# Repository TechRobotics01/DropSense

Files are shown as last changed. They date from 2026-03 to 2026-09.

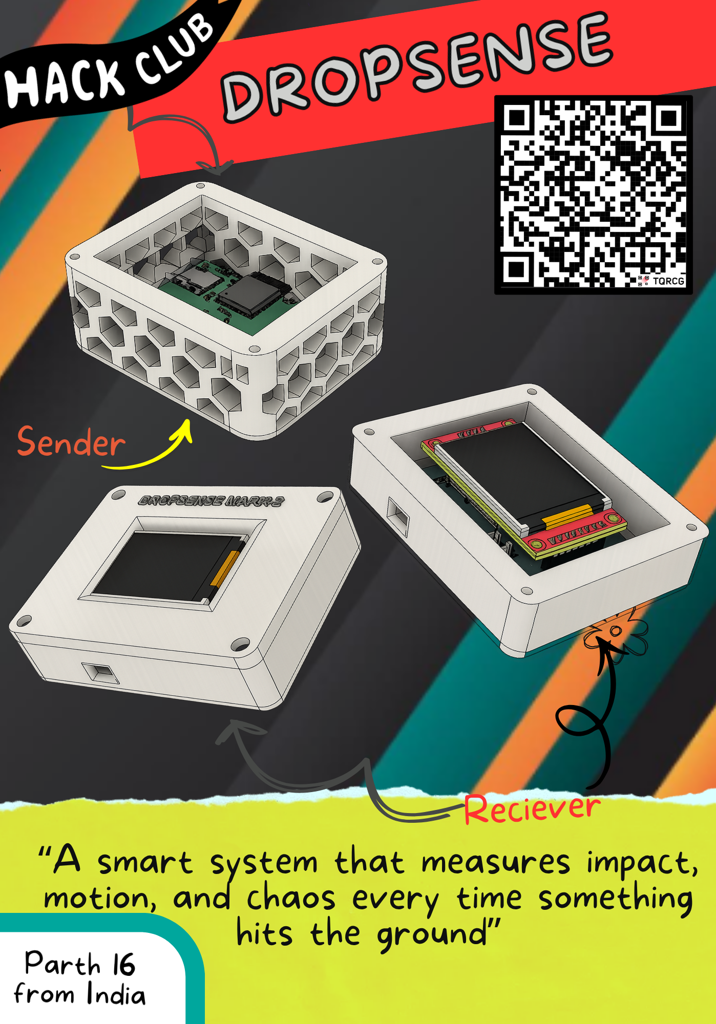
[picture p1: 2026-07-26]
Dropsense_V2/ZINE PAGE.png

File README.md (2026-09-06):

# DropSense
"what acctually happens when something drops"
dropsense answers that with data 

Dropsense is a wireless embedded system project which logs and transmits data in real time 
what type of data exactly?- it transmits the height from which it is dropped, the time period of the drop and the maximum Gforce which the device accelerated to during the impact .

Basically it consists of two parts the sender and the reciever 

# IMPORTANT POINT FOR THE REVIEWER
PLEASE CONSIDER THIS AS A DIGITAL DESIGN ONLY I DO NOT MEAN TO SUBMIT IT AS A IRL BUILD BUT A DIGITAL 2ND ITERATION OF THE PROJECT 
WHEN I BUILT THIS PROJECT IRL IT DID NOT WORK NOT BECAUSE IT WASN'T DESIGNED PROPERLY BUT BECAUSE AN IC FAILED AND WHICH I AM NOT ABLE TO REPLACE BECAUSE IT IS EXTREMELY COSTLY SO PLEASE CONSIDER THIS AS A DIGITAL DESIGN AND APPROVE IT 

# SENDER 
the sender consists of a custom made pcb which has a an esp32 s3 wroom 1 module an microsd card holder and a mpu6050(smd)
the sender will read the data and log it in sd card module and upomn impact that is g force greater than 5Gs then it will send info about the drop(height,time period etc) to the reciever btw this all is battery operated and it has a custom bms to power the pcb





This devise has hexagonal walls because they are better at abosrbing impacts!

# RECIEVER 
The reciever consists of an esp32 s3 wroom1 module and also an 1.8 inch tft display along with a custom made BMS for charging the battery which powers the pcb 
and the display shows all the info about the drop when it recieves the data fropm the sender 






# IRL BUILD 
## SENDER



## RECIEVER



## ZINE PAGE
DROPSENSE (2)

# Hardware
This device consists of 
1. MPU6050
2. Esp32-S3 module (not the development board)
3. sd card module 
4. custom BMS circuit
5. A small Li-Ion batter
6. 1.8 inch tft display 

All these parts will be on a custom made PCB whcih will be be enclosed inside a 3D printed case made out of TPU (you may also use PETG or CF-NYLON for added durability)

## THIS DEVICE HAS AN ERROR OF +-1CM FOR HEIGHT WHICH IS AM EXTREMELY LOW ERROR ##

# software
This was designed using the following softwares 

1. **Fusion360** for the 3d designing of the case
2. **KiCad** for the PCB design of this device

## CONTROL LOGIC
  1. in the prototyping stage
  2. The MPU6050 reads the values at a very high speed
  3. and then the valuse are logged into the sd card in a .csv file format
  4. then for prototyping the .csv file was read and analyzed
  5. figured out the threshold values such ad the gForce values which are required for automatic triggering and logging of data
  6. for eg when the device approached near 0 gForce vaklues the device is considered in a freefall and then the mpu605 starts to log the values in the sd card module and when the impact happend and the gForce stabelized at around 1Gfprce we can consider the device is stationary again and the Esp32 enters deep sleep mode again to save battery power
  7. the .csv file can then be used to plot graphs in different types of softwares for crash analysis
  8. also the crutial values such as drop height and maximum gForce of the crashb and the time time from falling to the crash is printed on the screen of the reciever 

## APPLICATIONS 
**this device can be used and applicated in places where gForce or acceleration and decelleration needs to be preciself analyzed**
1. drone crash analysis simply mount this device onto a drone and it will automaticaklly log the data when the drone crashes 
2. it can also be used in car crash analysis
3. this device acts as a black box for analysuis 

# credits (for R&D of this device)
google.com
https://randomnerdtutorials.com/arduino-mpu-6050-accelerometer-gyroscope/
Adafruit (use for taking out the values from mpu6050)
random nerd tutorials 
grabcad for the 3d step files of the tft and micro usb

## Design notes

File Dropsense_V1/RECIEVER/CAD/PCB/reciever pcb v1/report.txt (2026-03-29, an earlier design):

Plotted to 'C:\Users\DELL\Desktop\MISSION FALLOUT\DropSense\Dropsense_V1\RECIEVER\CAD\PCB\reciever pcb v1\reciever pcb v1-F_Cu.gbr'.
Plotted to 'C:\Users\DELL\Desktop\MISSION FALLOUT\DropSense\Dropsense_V1\RECIEVER\CAD\PCB\reciever pcb v1\reciever pcb v1-B_Cu.gbr'.
Plotted to 'C:\Users\DELL\Desktop\MISSION FALLOUT\DropSense\Dropsense_V1\RECIEVER\CAD\PCB\reciever pcb v1\reciever pcb v1-F_Paste.gbr'.
Plotted to 'C:\Users\DELL\Desktop\MISSION FALLOUT\DropSense\Dropsense_V1\RECIEVER\CAD\PCB\reciever pcb v1\reciever pcb v1-B_Paste.gbr'.
Plotted to 'C:\Users\DELL\Desktop\MISSION FALLOUT\DropSense\Dropsense_V1\RECIEVER\CAD\PCB\reciever pcb v1\reciever pcb v1-F_Silkscreen.gbr'.
Plotted to 'C:\Users\DELL\Desktop\MISSION FALLOUT\DropSense\Dropsense_V1\RECIEVER\CAD\PCB\reciever pcb v1\reciever pcb v1-B_Silkscreen.gbr'.
Plotted to 'C:\Users\DELL\Desktop\MISSION FALLOUT\DropSense\Dropsense_V1\RECIEVER\CAD\PCB\reciever pcb v1\reciever pcb v1-F_Mask.gbr'.
Plotted to 'C:\Users\DELL\Desktop\MISSION FALLOUT\DropSense\Dropsense_V1\RECIEVER\CAD\PCB\reciever pcb v1\reciever pcb v1-B_Mask.gbr'.
Plotted to 'C:\Users\DELL\Desktop\MISSION FALLOUT\DropSense\Dropsense_V1\RECIEVER\CAD\PCB\reciever pcb v1\reciever pcb v1-Edge_Cuts.gbr'.
Created Gerber job file 'C:\Users\DELL\Desktop\MISSION FALLOUT\DropSense\Dropsense_V1\RECIEVER\CAD\PCB\reciever pcb v1\reciever pcb v1-job.gbrjob'.
Info: Done.
Info: Done.

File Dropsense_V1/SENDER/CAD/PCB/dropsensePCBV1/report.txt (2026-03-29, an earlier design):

Plotted to 'C:\Users\DELL\Desktop\MISSION FALLOUT\DropSense\Dropsense_V1\SENDER\CAD\PCB\FINAL PERFECTED PCB FILE\dropsensePCBV1-F_Cu.gbr'.
Plotted to 'C:\Users\DELL\Desktop\MISSION FALLOUT\DropSense\Dropsense_V1\SENDER\CAD\PCB\FINAL PERFECTED PCB FILE\dropsensePCBV1-B_Cu.gbr'.
Plotted to 'C:\Users\DELL\Desktop\MISSION FALLOUT\DropSense\Dropsense_V1\SENDER\CAD\PCB\FINAL PERFECTED PCB FILE\dropsensePCBV1-F_Paste.gbr'.
Plotted to 'C:\Users\DELL\Desktop\MISSION FALLOUT\DropSense\Dropsense_V1\SENDER\CAD\PCB\FINAL PERFECTED PCB FILE\dropsensePCBV1-B_Paste.gbr'.
Plotted to 'C:\Users\DELL\Desktop\MISSION FALLOUT\DropSense\Dropsense_V1\SENDER\CAD\PCB\FINAL PERFECTED PCB FILE\dropsensePCBV1-F_Silkscreen.gbr'.
Plotted to 'C:\Users\DELL\Desktop\MISSION FALLOUT\DropSense\Dropsense_V1\SENDER\CAD\PCB\FINAL PERFECTED PCB FILE\dropsensePCBV1-B_Silkscreen.gbr'.
Plotted to 'C:\Users\DELL\Desktop\MISSION FALLOUT\DropSense\Dropsense_V1\SENDER\CAD\PCB\FINAL PERFECTED PCB FILE\dropsensePCBV1-F_Mask.gbr'.
Plotted to 'C:\Users\DELL\Desktop\MISSION FALLOUT\DropSense\Dropsense_V1\SENDER\CAD\PCB\FINAL PERFECTED PCB FILE\dropsensePCBV1-B_Mask.gbr'.
Plotted to 'C:\Users\DELL\Desktop\MISSION FALLOUT\DropSense\Dropsense_V1\SENDER\CAD\PCB\FINAL PERFECTED PCB FILE\dropsensePCBV1-Edge_Cuts.gbr'.
Created Gerber job file 'C:\Users\DELL\Desktop\MISSION FALLOUT\DropSense\Dropsense_V1\SENDER\CAD\PCB\FINAL PERFECTED PCB FILE\dropsensePCBV1-job.gbrjob'.
Info: Done.
Info: Done.

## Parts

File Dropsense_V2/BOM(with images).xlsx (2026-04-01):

Component | Quantity needed | Quantity purchased | Unit pricce($) | Total cost($) | Product link
100nF ±10% 50V Ceramic Capacitor X7R 0805 | 10 | 100 | 0.0051 | 0.51 | https://www.lcsc.com/product-detail/C49678.html
10uF ±10% 50V Ceramic Capacitor X5R 0805 | 10 | 50 | 0.072 | 3.6 | https://www.lcsc.com/product-detail/C440198.html
100uF ±20% 6.3V Ceramic Capacitor X5R 0805 | 10 | 20 | 0.2368 | 4.74 | https://www.lcsc.com/product-detail/C141660.html
Diode 40V 500mA Surface Mount 0805 | 10 | 10 | 0.1649 | 1.65 | https://www.lcsc.com/product-detail/C28323.html
Green 520nm LED Indication - Discrete 2.5V~3.6V 0805 | 1 | 30 | 0.0217 | 0.65 | https://www.lcsc.com/product-detail/C143774.html
Red 645nm LED Indication - Discrete 1.8V~2.4V 0805 | 1 | 100 | 0.0079 | 0.79 | https://www.lcsc.com/product-detail/C84260.html
SMD USB, DVI, HDMI Connector Adapters RoHS | 1 | 10 | 0.0828 | 0.83 | https://www.lcsc.com/product-detail/C19171391.html
Connector Header 2 position 2.5mm Pitch 3A Through Hole -25℃~+85℃ | 2 | 20 | 0.0373 | 0.75 | https://www.lcsc.com/product-detail/C53121380.html
330Ω ±1% 125mW 0805 Thick Film Resistor | 2 | 100 | 0.0023 | 0.23 | https://www.lcsc.com/product-detail/C158012.html
1.2Ω ±1% 125mW 0805 Thick Film Resistor | 2 | 100 | 0.0027 | 0.27 | https://www.lcsc.com/product-detail/C17630.html
4.7Ω ±1% 125mW 0805 Thick Film Resistor | 1 | 100 | 0.0027 | 0.27 | https://www.lcsc.com/product-detail/C2933356.html
10Ω 125mW 150V Thick Film Resistor ±1% ±200ppm/℃ 0805 Chip Resistor - Surface Mount RoHS | 2 | 100 | 0.008 | 0.8 | https://www.lcsc.com/product-detail/C2933459.html
Micro SD card (TF card) Connector and Ejector Push-Push Surface Mount | 2 | 2 | 1.6306 | 3.26 | https://www.lcsc.com/product-detail/C96347.html
QFN-24-EP(4x4) Accelerometers RoHS | 2 | 1 | 7.9306 | 7.93 | https://www.lcsc.com/product-detail/C114218.html
2.4GHz ESP32-S3 On-board PCB Antenna -103.5dBm SMD,25.5x18mm RF Transceiver Modules and Modems RoHS | 1 | 2 | 4.4597 | 8.92 | https://www.lcsc.com/product-detail/C24112.html
Lithium Battery 1A ESOP-8 Battery Management RoHS | 2 | 10 | 0.1828 | 1.83 | https://www.lcsc.com/product-detail/C2913197.html
3.3V 6V Positive Fixed SOT-23-5 Voltage Regulators - Linear, Low Drop Out (LDO) Regulators RoHS | 2 | 10 | 0.0491 | 0.49 | https://www.lcsc.com/product-detail/C16581.html
1uF ±10% 50V Ceramic Capacitor X7R 0805 | 2 | 100 | 0.0138 | 1.38 | https://www.lcsc.com/product-detail/C82942.html
WLY752530 3.7V 500mAh 1S LiPo Battery | 2 | 2 | 2.79 | 5.58 | https://robu.in/product/500mah-pcm-protected-micro-li-po-battery/
LCSC SHIPPING COST (CHEAPEST OPTION UPS) | 1 | 1 | $29.24 | 29.24
PCBs FABRICATION (from LION CIRCUITS )(sender and reciever both included) | 2 | 10 | 9.6 | 22.4(inc. GST) | https://order.lioncircuits.com/cart
1.8inch tft display | 1 | N/A | N/A | N/A | Self sourced
YIHUA 946D-IV Mini Soldering Hot Plate 400°C | 1 | 1 | 20.37 | 20.37 | https://babaocamachine.com/product/yihua-946d-iv-mini-soldering-hot-plate-400c-adjustable-temp-c-f-conversion/
solder paste | 1 | 1 | 1.8 | 1.8 | https://makerbazar.in/products/mechanic-10cc-lead-free-no-clean-solder-flux-paste-syring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
 |  |  | TOTAL COST = | 116.49

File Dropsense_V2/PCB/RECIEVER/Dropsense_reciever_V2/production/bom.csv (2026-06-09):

Designator | Footprint | Quantity | Value | LCSC Part #
C1, C2, C3, C4, C6 | 0805 | 5 | 10uF
C10, C5 | 0805 | 2 | 0.1uF
C12 | 0805 | 1 | 1uF
D3 | 0805 | 1 | red
D4 | 0805 | 1 | grn
EN1, IO0 | SW_Push_1P1T-SH_NO_CK_KMR2xxG | 2 | SW_Push
J1 | USB_Micro-B_Amphenol_10118194-0001LF_Horizontal | 1 | USB_B_Micro
J2 | JST_XH_B2B-XH-A_1x02_P2.50mm_Vertical | 1 | Battery_conn
J3 | PinSocket_1x08_P2.54mm_Vertical | 1 | 1.8inch TFT connector
R1 | 0805 | 1 | 3.3kR
R10, R11 | 0805 | 2 | 100kR
R2, R3 | 0805 | 2 | 1kR
R4, R5 | 0805 | 2 | 22R
R6, R7, R9 | 0805 | 3 | 10kR
R8 | 0805 | 1 | 330R
U1 | SOIC-8-1EP_3.9x4.9mm_P1.27mm_EP2.41x3.3mm_ThermalVias | 1 | TP4056-42-ESOP8
U2 | SOT-23-5 | 1 | ME6211C33M5
U3 | ESP32-S3-WROOM-1 | 1 | ESP32-S3-WROOM-1

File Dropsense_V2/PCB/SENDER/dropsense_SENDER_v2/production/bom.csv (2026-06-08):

Designator | Footprint | Quantity | Value | LCSC Part #
C1_2, C1, C11, C13, C3, C8 | 0805 | 6 | 10uF
C10, C2, C6, C7, C9 | 0805 | 5 | 0.1uF
C12 | 0805 | 1 | 1uF
C4 | 0805 | 1 | 2.2nF
C5 | 0805 | 1 | 100nF
D1 | 0805 | 1 | GREEN
D2 | 0805 | 1 | RED
EN1, IO0 | SW_Push_1P1T-SH_NO_CK_KMR2xxG | 2 | SW_Push
J1 | USB_Micro-B_Molex-105017-0001 | 1 | USB_B_Micro
J2 | JST_XH_B2B-XH-A_1x02_P2.50mm_Vertical | 1 | Conn_01x02
J3 | microSD_HC_Hirose_DM3AT-SF-PEJM5 | 1 | Micro_SD_Card_Det_Hirose_DM3AT
J4 | PinHeader_1x06_P2.54mm_Vertical | 1 | Conn_01x06_Pin
R1 | 0805 | 1 | 3.3kR
R10, R11 | 0805 | 2 | 100kR
R12, R13 | 0805 | 2 | 22R
R2, R3 | 0805 | 2 | 330R
R4, R5, R8, R9 | 0805 | 4 | 10kR
R6, R7 | 0805 | 2 | 4.7kR
U1 | ESP32-S3-WROOM-1 | 1 | ESP32-S3-WROOM-1
U2 | SOIC-8-1EP_3.9x4.9mm_P1.27mm_EP2.41x3.3mm_ThermalVias | 1 | TP4056-42-ESOP8
U3 | SOT-23-5 | 1 | ME6211C33M5
U4 | InvenSense_QFN-24_4x4mm_P0.5mm | 1 | MPU-6050

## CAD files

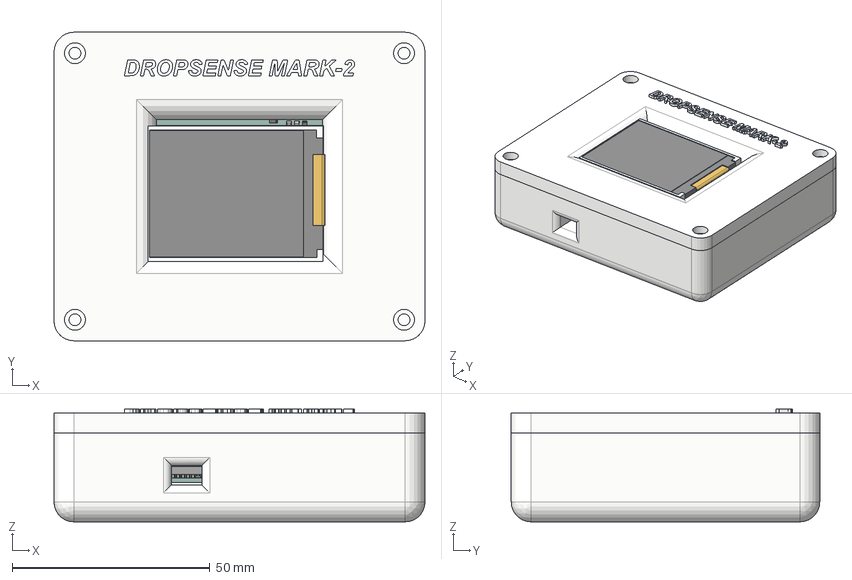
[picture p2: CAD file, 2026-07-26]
Dropsense_V2/CAD/RECIEVER/Reciever files/Dropsense Makr-2 reciever assembly v1.step
93.8 x 78.0 x 28.5 mm
R_0805_2012Metric x 11
PinSocket_1x08_P2.54mm_Vertical
C_0805_2012Metric x 8
ESP32-S3-WROOM-1
SW_Push_1P1T-SH_NO_CK_KMR2xxG x 2
JST_XH_B2B-XH-A_1x02_P2.50mm_Vertical
SOT-23-5
LED_0805_2012Metric x 2
dropsense_reciever_v2_PCB
Board~fHK2
TopSilkscreen~fHK2
BottomSilkscreen~fHK2
R0603~R0603~fHK2 x 4
SOT-23-3_L2.9-W1.3-P1.90-LS2.4-BR~SOT-23-3P_L2.9-W1.3-H1.0-LS2.4-P0.9 5~fHK2
HDR-TH_4P-P2.54-V-M~HDR-TH_4P-P2.54-M-LI-1X4P~fHK2
SD-CARD-SMD_SD-CARD-11P~SD-CARD-SMD_SD-CARD-11P~fHK2
C0603~C0603_L1.6-W0.8-H0.8~fHK2
HDR-TH_8P-P2.54-V-M~HDR-TH_8P-P2.54-V-M~fHK2
Dropsense mark-2 reciever part-1
Dropsense Mark-2 reciever part-2

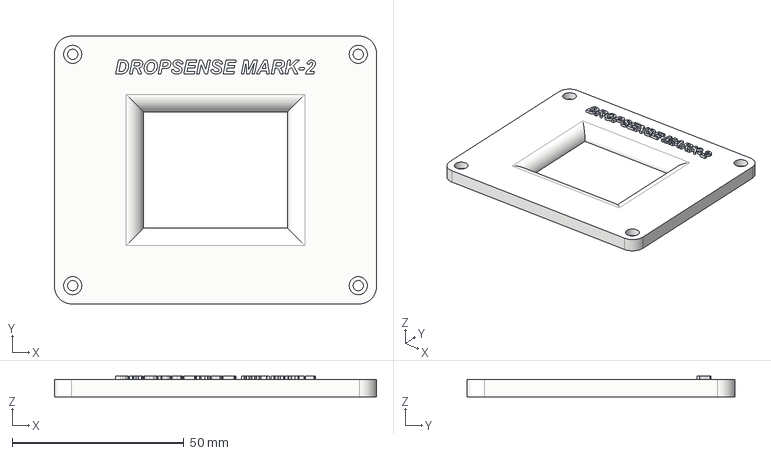
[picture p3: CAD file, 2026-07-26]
Dropsense_V2/CAD/RECIEVER/Reciever files/Dropsense Mark-2 reciever part-2 v8.step
93.8 x 78.0 x 6.00 mm

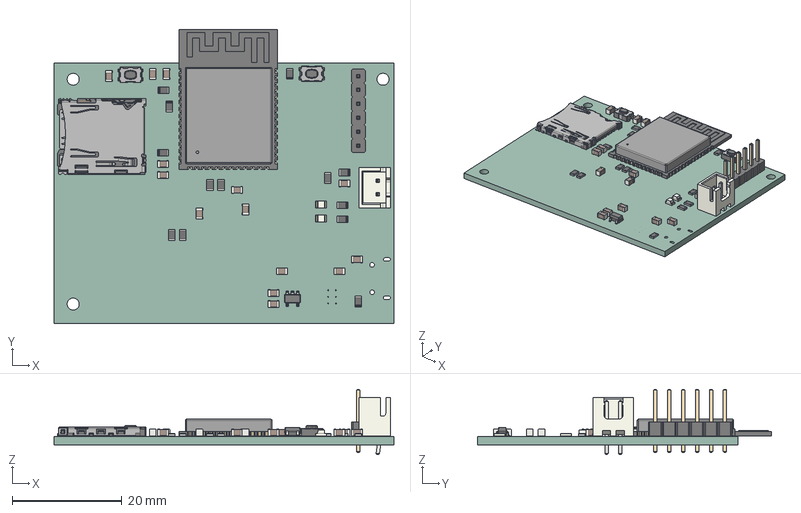
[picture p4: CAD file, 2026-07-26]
Dropsense_V2/CAD/SENDER/dropsense_v2.step
62.0 x 53.5 x 11.9 mm
C_0805_2012Metric x 14
R_0805_2012Metric x 13
SOT-23-5
LED_0805_2012Metric x 2
SW_Push_1P1T-SH_NO_CK_KMR2xxG x 2
ESP32-S3-WROOM-1
microSD_HC_Hirose_DM3AT-SF-PEJM5
PinHeader_1x06_P2.54mm_Vertical
JST_XH_B2B-XH-A_1x02_P2.50mm_Vertical
dropsense_v2_PCB

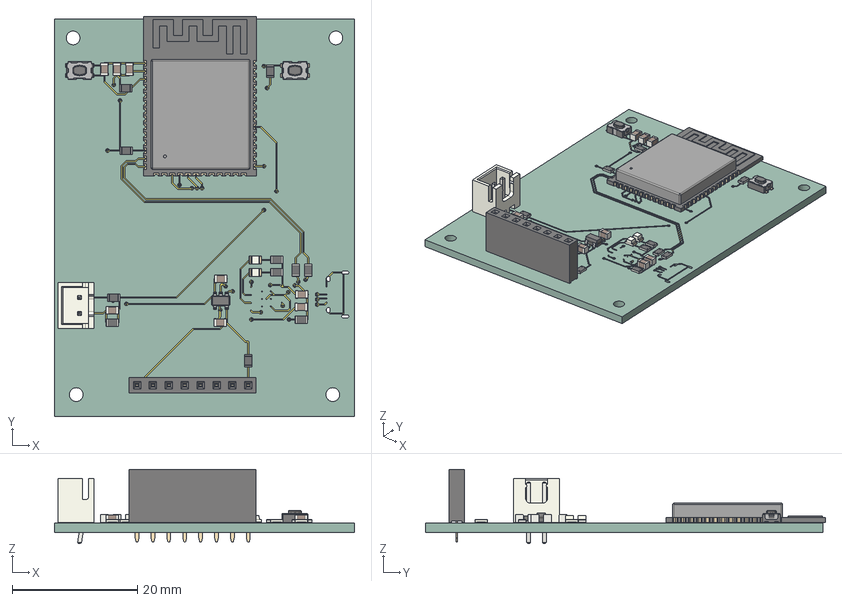
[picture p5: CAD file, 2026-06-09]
Dropsense_V2/PCB/RECIEVER/Dropsense_reciever_V2/RECIEVER STEP FILE/dropsense_reciever_v2.step
48.0 x 63.9 x 11.9 mm
R_0805_2012Metric x 11
PinSocket_1x08_P2.54mm_Vertical
C_0805_2012Metric x 8
ESP32-S3-WROOM-1
SW_Push_1P1T-SH_NO_CK_KMR2xxG x 2
JST_XH_B2B-XH-A_1x02_P2.50mm_Vertical
SOT-23-5
LED_0805_2012Metric x 2
dropsense_reciever_v2_copper
dropsense_reciever_v2_via
dropsense_reciever_v2_PCB

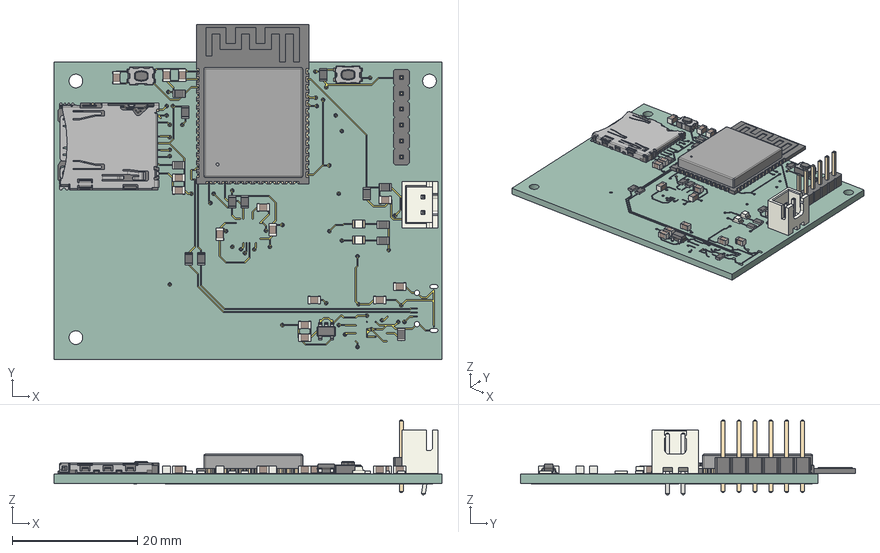
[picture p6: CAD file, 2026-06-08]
Dropsense_V2/PCB/SENDER/dropsense_SENDER_v2/PCB STEP FILE/dropsense_v2.step
62.0 x 53.5 x 11.9 mm
C_0805_2012Metric x 14
R_0805_2012Metric x 13
SOT-23-5
LED_0805_2012Metric x 2
SW_Push_1P1T-SH_NO_CK_KMR2xxG x 2
ESP32-S3-WROOM-1
microSD_HC_Hirose_DM3AT-SF-PEJM5
PinHeader_1x06_P2.54mm_Vertical
JST_XH_B2B-XH-A_1x02_P2.50mm_Vertical
dropsense_v2_copper
dropsense_v2_via
dropsense_v2_PCB

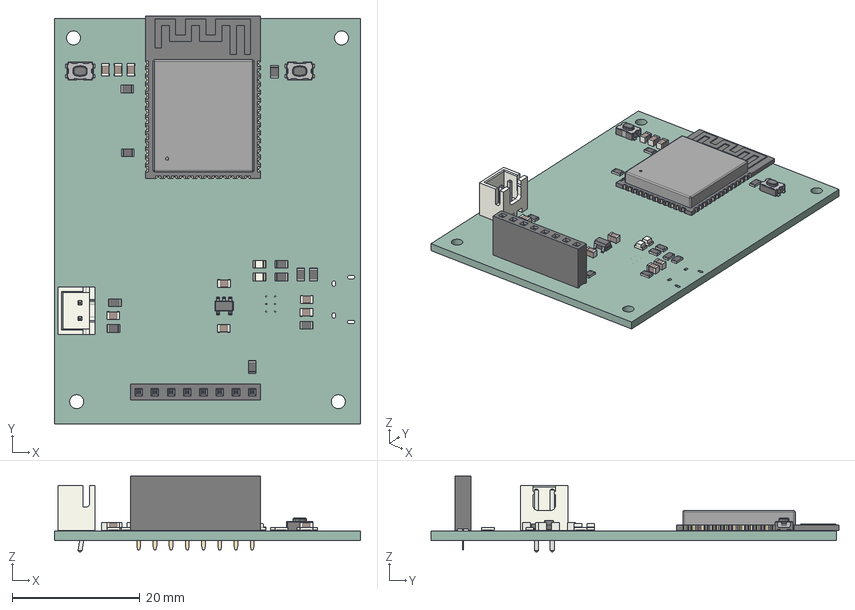
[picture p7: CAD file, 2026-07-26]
Dropsense_V2/CAD/RECIEVER/Reciever files/dropsense_reciever_pcb.step
48.0 x 63.9 x 11.9 mm
R_0805_2012Metric x 11
PinSocket_1x08_P2.54mm_Vertical
C_0805_2012Metric x 8
ESP32-S3-WROOM-1
SW_Push_1P1T-SH_NO_CK_KMR2xxG x 2
JST_XH_B2B-XH-A_1x02_P2.50mm_Vertical
SOT-23-5
LED_0805_2012Metric x 2
dropsense_reciever_v2_PCB

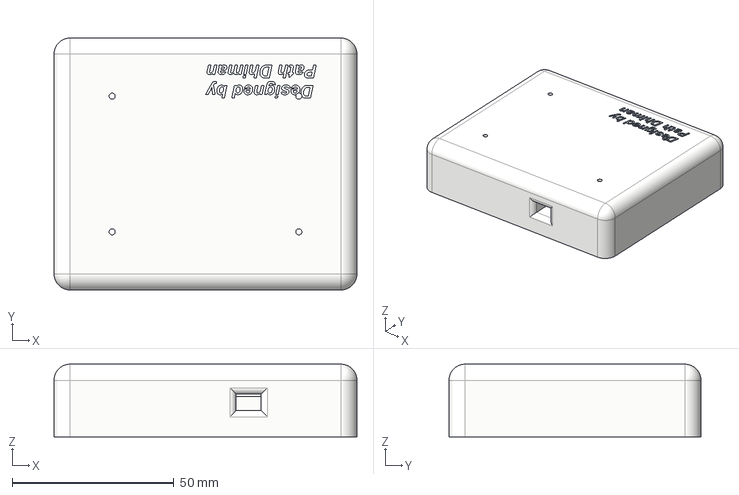
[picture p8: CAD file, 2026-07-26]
Dropsense_V2/CAD/RECIEVER/Reciever files/Dropsense mark-2 reciever part-1 v5.step
93.8 x 78.0 x 22.5 mm

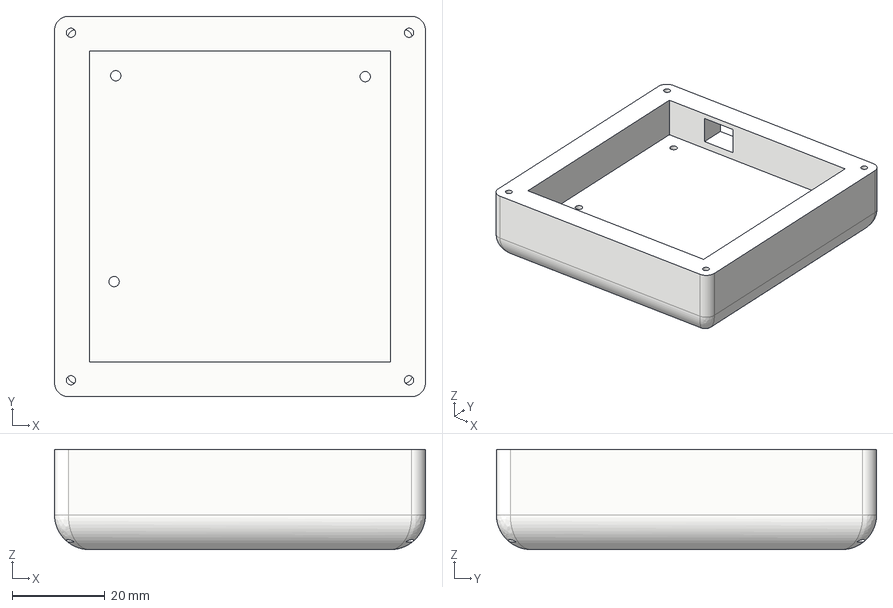
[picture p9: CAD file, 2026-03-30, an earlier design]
Dropsense_V1/RECIEVER/CAD/3D DESIGN/Dropsense reciever 3d print part 1/Dropsense reciever pcb case v14.step
80.0 x 82.0 x 21.6 mm

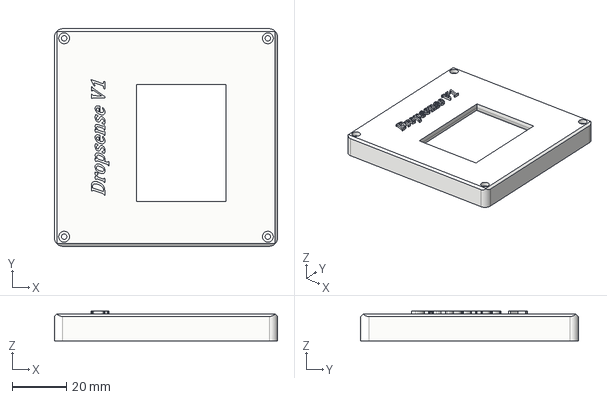
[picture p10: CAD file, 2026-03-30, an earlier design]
Dropsense_V1/RECIEVER/CAD/3D DESIGN/Dropsense reciever 3d print part 2/dropsense reciever lid v1 v12.step
82.0 x 80.0 x 11.0 mm

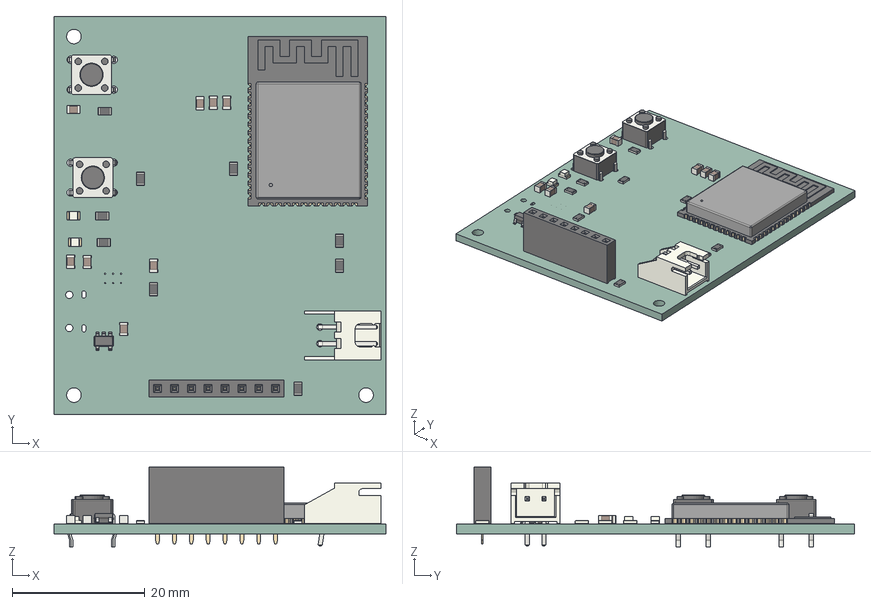
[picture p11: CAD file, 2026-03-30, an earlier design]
Dropsense_V1/RECIEVER/CAD/PCB/reciever pcb v1.step
50.0 x 60.0 x 12.0 mm
JST_XH_S2B-XH-A_1x02_P2.50mm_Horizontal
R_0805_2012Metric x 9
C_0805_2012Metric x 8
SOT-23-5
LED_0805_2012Metric x 2
ESP32-S3-WROOM-1
SW_PUSH_6mm_H4.3mm x 2
PinSocket_1x08_P2.54mm_Vertical
reciever pcb v1_PCB

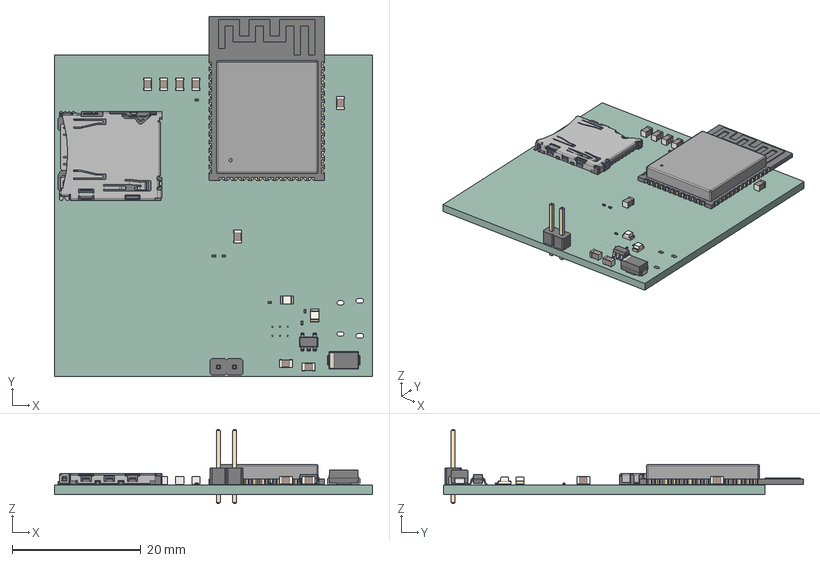
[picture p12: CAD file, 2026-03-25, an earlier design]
Dropsense_V1/SENDER/CAD/3D design/dropsensePCBV1.step
49.5 x 56.0 x 11.5 mm
C_0805_2012Metric x 8
R_0201_0603Metric x 6
PinHeader_1x02_P2.54mm_Vertical
microSD_HC_Hirose_DM3AT-SF-PEJM5
LED_0805_2012Metric x 2
ESP32-S3-WROOM-1
SOT-23-5
D_SMA
dropsensePCBV1_PCB

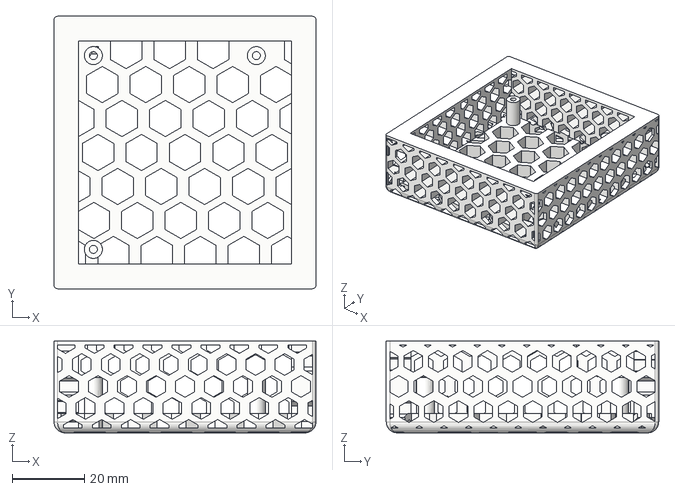
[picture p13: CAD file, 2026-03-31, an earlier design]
Dropsense_V1/SENDER/CAD/3D design/enclosure part 1/Dropsense sender pcn case part 1 v8.step
72.3 x 75.2 x 25.3 mm

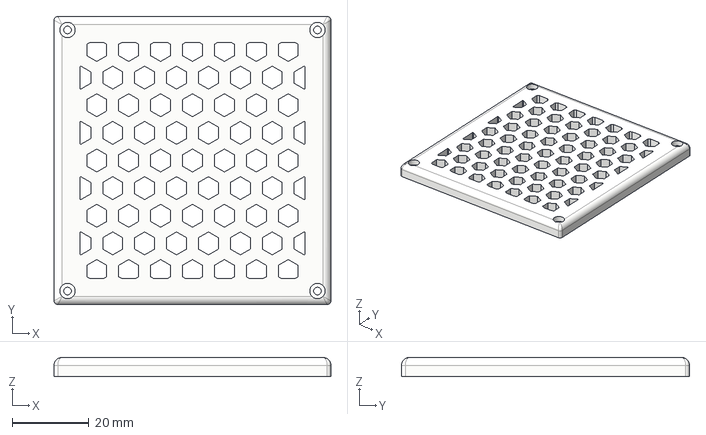
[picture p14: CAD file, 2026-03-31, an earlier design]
Dropsense_V1/SENDER/CAD/3D design/enclosure part 2/Dropsense sender pcb 3d enclosure part 2 v4.step
72.3 x 75.2 x 5.00 mm

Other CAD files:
Dropsense_V1/RECIEVER/CAD/PCB/reciever pcb v1/reciever pcb v1.step
Dropsense_V1/RECIEVER/CAD/3D DESIGN/Dropsense reciever 3d print part 1/Dropsense reciever pcb case v14.f3d
Dropsense_V1/RECIEVER/CAD/3D DESIGN/Dropsense reciever 3d print part 2/dropsense reciever lid v1 v12.f3d
Dropsense_V2/CAD/RECIEVER/Reciever files/Dropsense Mark-2 reciever part-2 v8.f3d
Dropsense_V2/CAD/RECIEVER/Reciever files/Dropsense mark-2 reciever part-1 v5.f3d

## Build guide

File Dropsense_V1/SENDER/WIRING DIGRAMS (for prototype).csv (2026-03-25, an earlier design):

WIRING with esp32 s3 (FOR PROTOTYPE)
MPU6050 |  | SD CARD MODULE
VCC | 5V | 3V3 | 3V3
GND | GND | GND | GND
SCL | GPIO22 | CS | GPIO5
SDA | GPIO21 | MISO | GPIO19
 |  | MOSI | GPIO23
 |  | CLK | GPIO18
### PLEASE OPEN THIS FILE IN MICROSOFT EXCEL FOR PROPER VIEWING ###

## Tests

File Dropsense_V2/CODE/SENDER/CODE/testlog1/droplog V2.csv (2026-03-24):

time | gForce | event
439 | 1.04 | stat
459 | 1.03 | stat
478 | 1.03 | stat
497 | 1.03 | stat
516 | 1.04 | stat
535 | 1.03 | stat
554 | 1.03 | stat
573 | 1.03 | stat
592 | 1.04 | stat
611 | 1.04 | stat
630 | 1.03 | stat
649 | 1.04 | stat
668 | 1.03 | stat
687 | 1.04 | stat
706 | 1.04 | stat
725 | 1.04 | stat
744 | 1.03 | stat
763 | 1.03 | stat
782 | 1.03 | stat
801 | 1.03 | stat
820 | 1.04 | stat
839 | 1.03 | stat
858 | 1.03 | stat
877 | 1.04 | stat
896 | 1.03 | stat
915 | 1.05 | stat
955 | 1.04 | stat
974 | 1.03 | stat
993 | 1.03 | stat
1012 | 1.04 | stat
1031 | 1.05 | stat
1050 | 1.04 | stat
1069 | 1.03 | stat
1091 | 1.04 | stat
1110 | 1.05 | stat
1129 | 1.04 | stat
1148 | 1.03 | stat
1167 | 1.03 | stat
1186 | 1.04 | stat
1205 | 1.04 | stat
1224 | 1.04 | stat
1243 | 1.04 | stat
1262 | 1.03 | stat
1281 | 1.05 | stat
1300 | 1.03 | stat
1319 | 1.04 | stat
1338 | 1.04 | stat
1357 | 1.05 | stat
1376 | 1.03 | stat
1395 | 1.04 | stat
1414 | 1.04 | stat
1433 | 1.03 | stat
1452 | 1.04 | stat
1471 | 1.04 | stat
1490 | 1.04 | stat
1509 | 1.04 | stat
1528 | 1.04 | stat
1547 | 1.04 | stat
1566 | 1.05 | stat
1585 | 1.04 | stat
1604 | 1.04 | stat
1623 | 1.04 | stat
1642 | 1.04 | stat
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

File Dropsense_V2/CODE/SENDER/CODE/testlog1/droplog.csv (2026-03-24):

time | gForce
568 | 1.02
592 | 1.02
616 | 1.03
640 | 1.03
664 | 1.03
688 | 1.03
712 | 1.03
736 | 1.03
760 | 1.03
784 | 1.03
808 | 1.03
832 | 1.04
856 | 1.03
880 | 1.03
904 | 1.04
928 | 1.03
952 | 1.03
976 | 1.02
1000 | 1.03
1024 | 1.03
1048 | 1.03
1072 | 1.04
1096 | 1.03
1120 | 1.04
1144 | 1.03
1168 | 1.04
1192 | 1.04
1216 | 1.03
1240 | 1.03
1264 | 1.03
1288 | 1.03
1312 | 1.03
1336 | 1.03
1360 | 1.03
1384 | 1.03
1408 | 1.04
1432 | 1.03
1456 | 1.03
1480 | 1.03
1504 | 1.03
1528 | 1.03
1552 | 1.03
1576 | 1.02
1600 | 1.03
1624 | 1.04
1648 | 1.03
1672 | 1.02
1695 | 1.04
1719 | 1.04
1743 | 1.03
1767 | 1.04
1791 | 1.04
1815 | 1.02
1839 | 1.03
1863 | 1.03
1887 | 1.03
1911 | 1.04
1935 | 1.03
1959 | 1.04
1983 | 1.04
2007 | 1.04
2031 | 1.04
2077 | 1.04
2101 | 1.04
2125 | 1.04
2149 | 1.04
2173 | 1.04
2197 | 1.03
2221 | 1.04
2245 | 1.03
2269 | 1.03
2293 | 1.04
2317 | 1.03
2341 | 1.03
2365 | 1.02
2389 | 1.03
2413 | 1.03
2437 | 1.03
2461 | 1.03
2485 | 1.03
2509 | 1.03
2533 | 1.02
2557 | 1.04
2581 | 1.03
2605 | 1.02
2629 | 1.04
2653 | 1.04
2677 | 1.03
2701 | 1.04
2725 | 1.03
2749 | 1.03
2773 | 1.03
2797 | 1.03
2821 | 1.04
2848 | 1.03
2872 | 1.04
2896 | 1.04
2920 | 1.03
2944 | 1.03
2968 | 1.04
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

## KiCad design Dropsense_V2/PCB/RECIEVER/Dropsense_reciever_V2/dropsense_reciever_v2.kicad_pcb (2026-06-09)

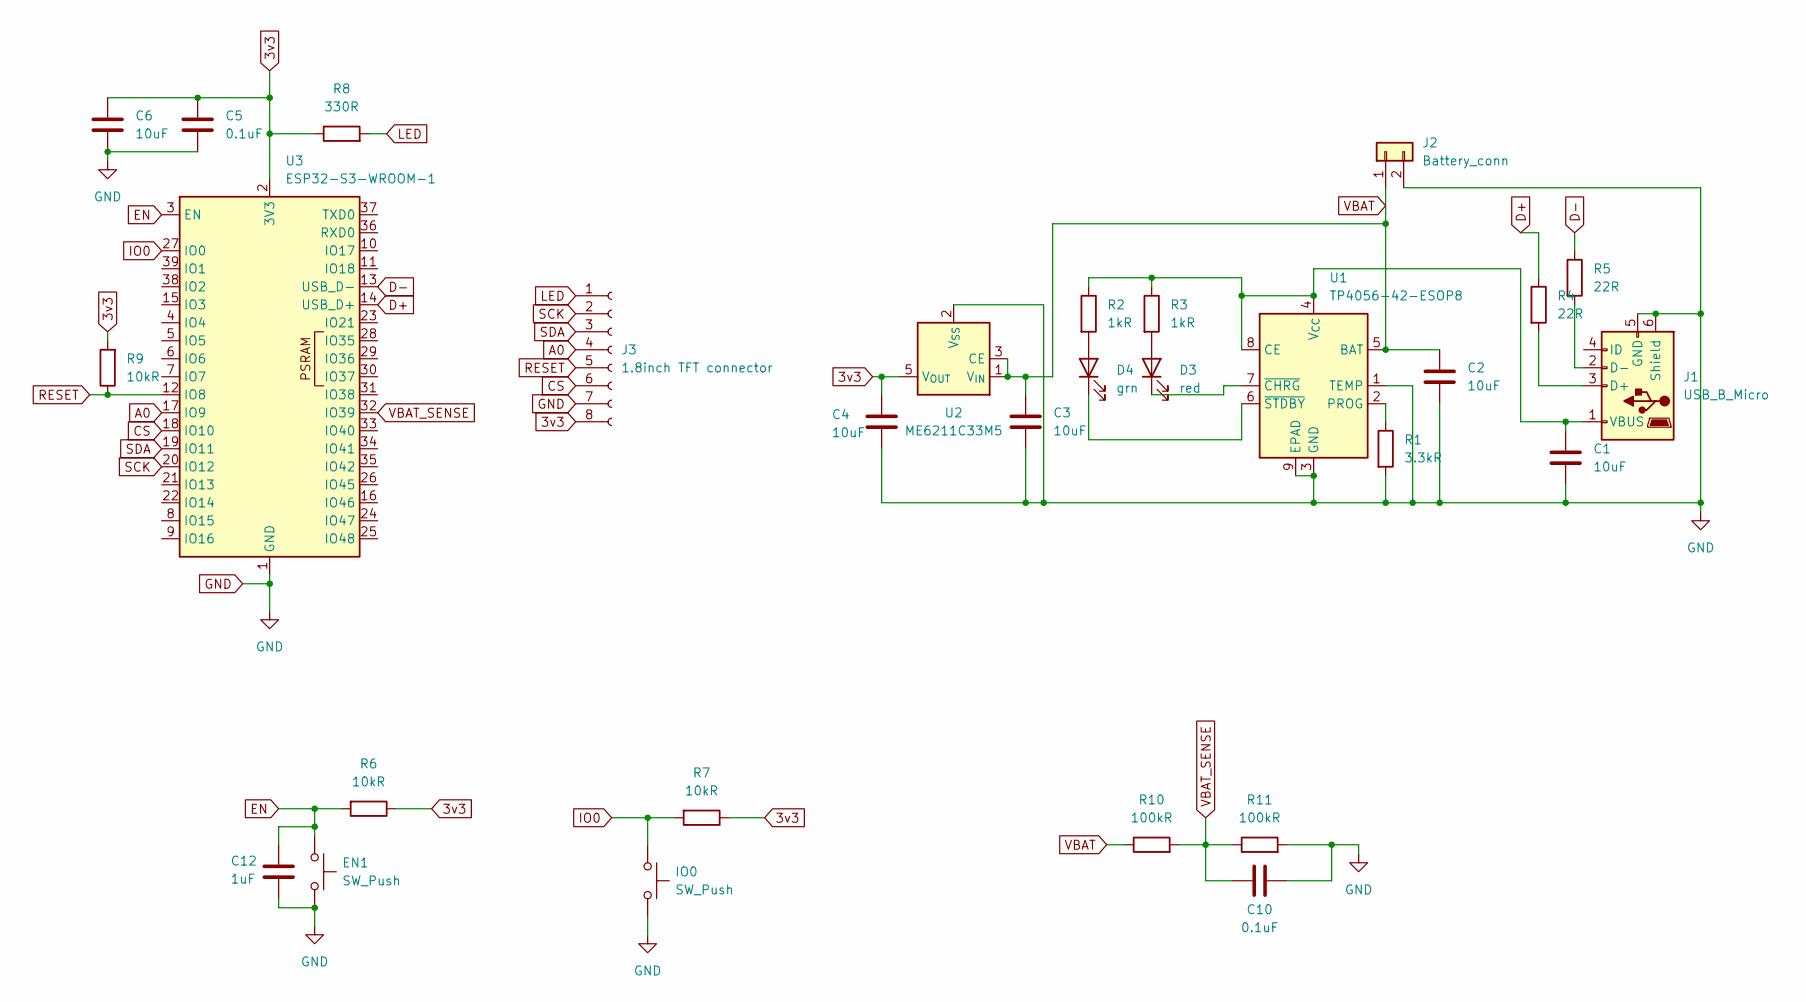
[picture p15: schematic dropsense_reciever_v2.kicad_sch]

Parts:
C1, C2, C3, C4, C6: 10uF; C_0805_2012Metric
C5, C10: 0.1uF; C_0805_2012Metric
C12: 1uF; C_0805_2012Metric
D3: red; LED_0805_2012Metric
D4: grn; LED_0805_2012Metric
EN1: SW_Push; SW_Push_1P1T-SH_NO_CK_KMR2xxG
IO0: SW_Push; SW_Push_1P1T-SH_NO_CK_KMR2xxG
J1: USB_B_Micro; USB_Micro-B_Amphenol_10118194-0001LF_Horizontal
J2: Battery_conn; JST_XH_B2B-XH-A_1x02_P2.50mm_Vertical
J3: 1.8inch TFT connector; PinSocket_1x08_P2.54mm_Vertical
R1: 3.3kR; R_0805_2012Metric
R2, R3: 1kR; R_0805_2012Metric
R4, R5: 22R; R_0805_2012Metric
R6, R7, R9: 10kR; R_0805_2012Metric
R8: 330R; R_0805_2012Metric
R10, R11: 100kR; R_0805_2012Metric
U1: TP4056-42-ESOP8; SOIC-8-1EP_3.9x4.9mm_P1.27mm_EP2.41x3.3mm_ThermalVias
U2: ME6211C33M5; SOT-23-5
U3: ESP32-S3-WROOM-1

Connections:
3v3: C4.1, C5.1, C6.1, J3.8, R6.1, R7.1, R8.1, R9.2, U2.5 (V_{OUT}), U3.2 (3V3)
A0: J3.4, U3.17 (IO9)
CS: J3.6, U3.18 (IO10)
D+: R4.1, U3.14 (USB_D+)
D-: R5.1, U3.13 (USB_D-)
EN: C12.1, EN1.1, R6.2, U3.3 (EN)
GND: C1.2, C2.2, C3.2, C4.2, C5.2, C6.2, C10.2, C12.2, EN1.2, IO0.2, J1.5 (GND), J1.6 (Shield), J2.2, J3.7, R1.2, R11.2, U1.1 (TEMP), U1.3 (GND), U1.9 (EPAD), U2.2 (V_{SS}), U3.1 (GND), U3.40 (GND), U3.41 (GND)
IO0: IO0.1, R7.2, U3.27 (IO0)
LED: J3.1, R8.2
unnamed: D3.2 (A), R3.2
unnamed: D3.1 (K), U1.7 (~CHRG)
unnamed: D4.2 (A), R2.2
unnamed: D4.1 (K), U1.6 (~STDBY)
unnamed: J1.3 (D+), R4.2
unnamed: J1.2 (D-), R5.2
unnamed: C1.1, J1.1 (VBUS), R2.1, R3.1, U1.4 (V_{CC}), U1.8 (CE)
unnamed: R1.1, U1.2 (PROG)
RESET: J3.5, R9.1, U3.12 (IO8)
SCK: J3.2, U3.20 (IO12)
SDA: J3.3, U3.19 (IO11)
VBAT: C2.1, C3.1, J2.1, R10.1, U1.5 (BAT), U2.1 (V_{IN}), U2.3 (CE)
VBAT_SENSE: C10.1, R10.2, R11.1, U3.32 (IO39)

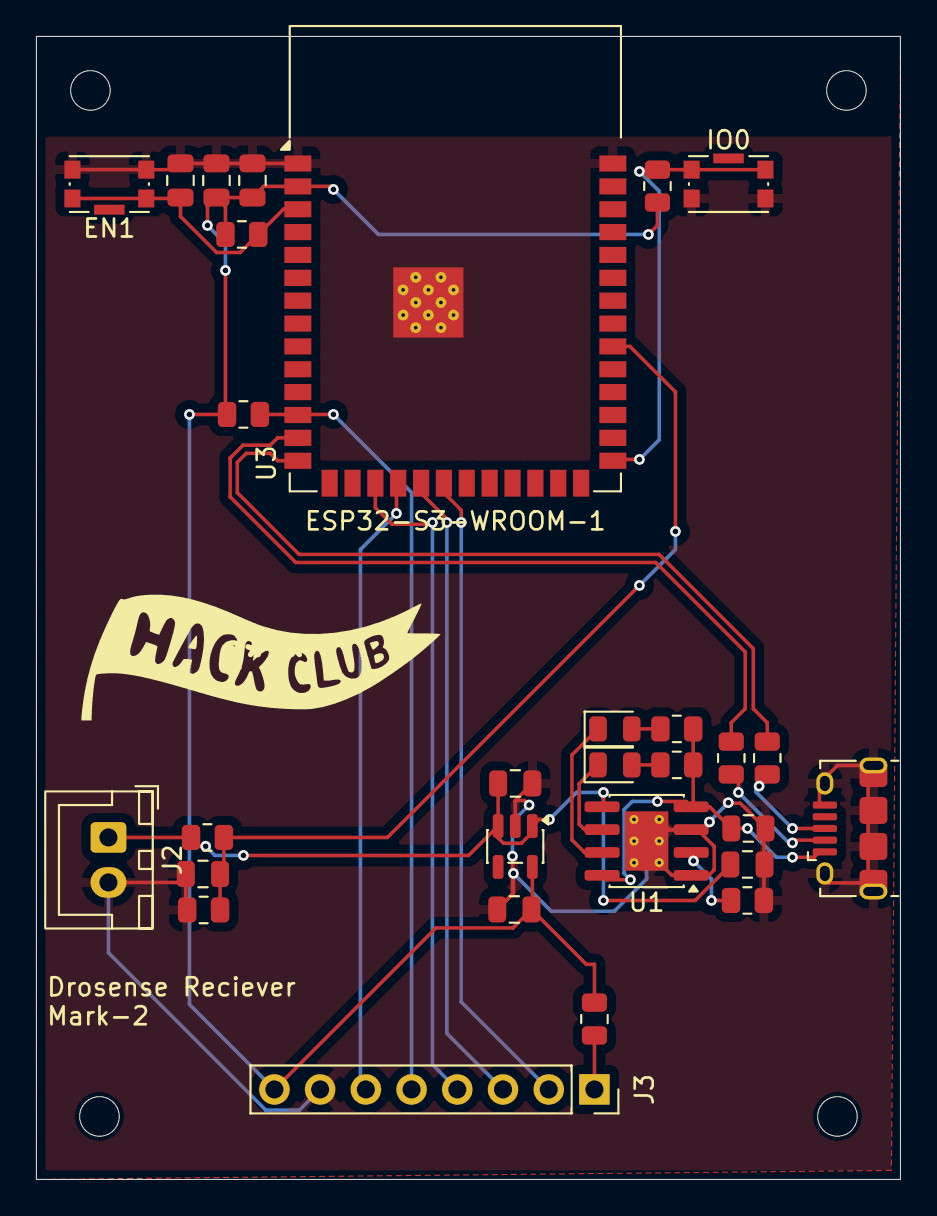
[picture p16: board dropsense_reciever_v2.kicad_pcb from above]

Board: 2 copper layers, 48.0 x 63.5 mm, 29 parts (0 on the bottom side), 22 nets.

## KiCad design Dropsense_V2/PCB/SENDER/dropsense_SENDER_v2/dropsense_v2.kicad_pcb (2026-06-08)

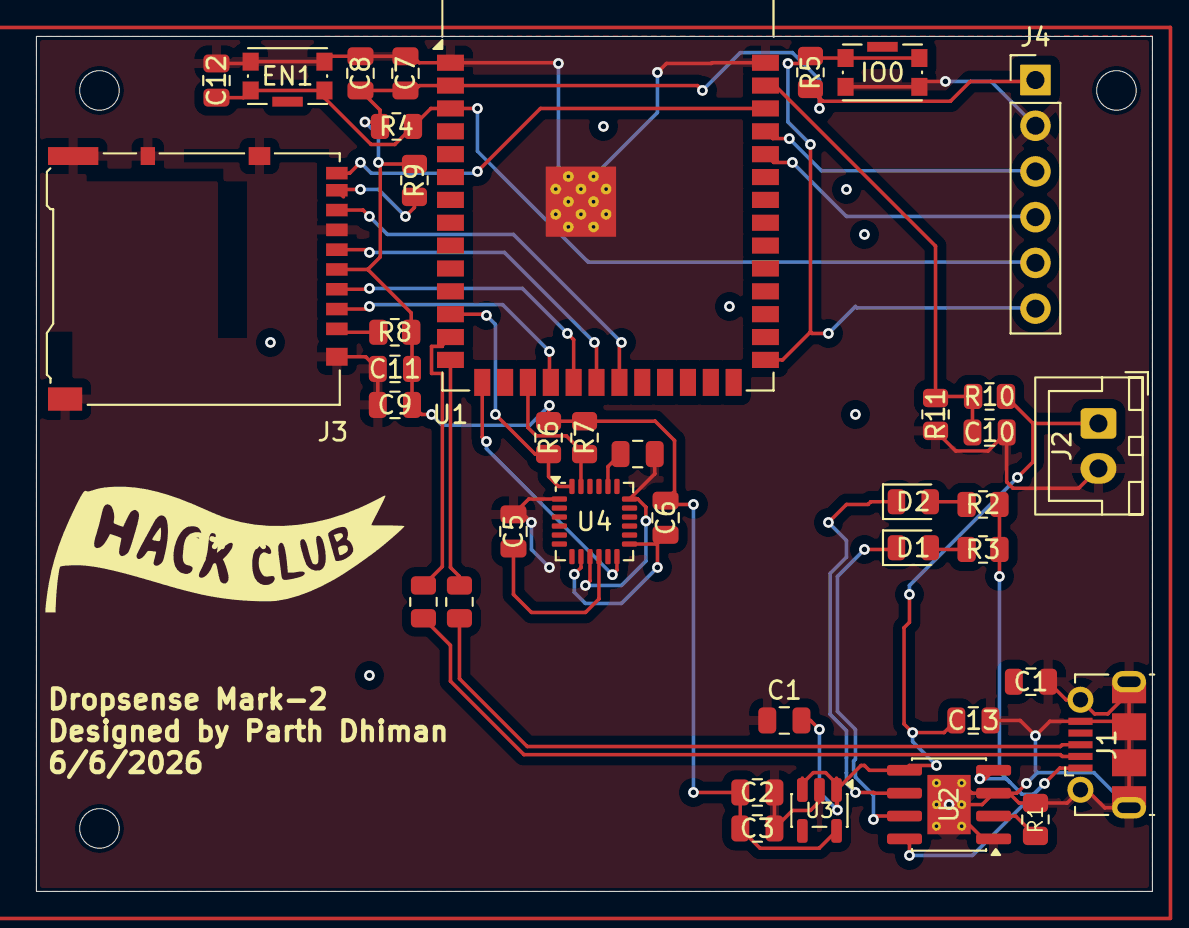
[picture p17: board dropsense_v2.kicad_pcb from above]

Board: 2 copper layers, 62.0 x 47.5 mm, 39 parts (0 on the bottom side), 31 nets.

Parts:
C1, C1#2, C3, C8, C11, C13: 10uF; C_0805_2012Metric
C2, C6, C7, C9, C10: 0.1uF; C_0805_2012Metric
C4: 2.2nF; C_0805_2012Metric
C5: 100nF; C_0805_2012Metric
C12: 1uF; C_0805_2012Metric
D1: GREEN; LED_0805_2012Metric
D2: RED; LED_0805_2012Metric
EN1: SW_Push; SW_Push_1P1T-SH_NO_CK_KMR2xxG
IO0: SW_Push; SW_Push_1P1T-SH_NO_CK_KMR2xxG
J1: USB_B_Micro; USB_Micro-B_Molex-105017-0001
J2: Conn_01x02; JST_XH_B2B-XH-A_1x02_P2.50mm_Vertical
J3: Micro_SD_Card_Det_Hirose_DM3AT; microSD_HC_Hirose_DM3AT-SF-PEJM5
J4: Conn_01x06_Pin; PinHeader_1x06_P2.54mm_Vertical
R1: 3.3kR; R_0805_2012Metric
R2, R3: 330R; R_0805_2012Metric
R4, R5, R8, R9: 10kR; R_0805_2012Metric
R6, R7: 4.7kR; R_0805_2012Metric
R10, R11: 100kR; R_0805_2012Metric
R12, R13: 22R; R_0805_2012Metric
U1: ESP32-S3-WROOM-1
U2: TP4056-42-ESOP8; SOIC-8-1EP_3.9x4.9mm_P1.27mm_EP2.41x3.3mm_ThermalVias
U3: ME6211C33M5; SOT-23-5
U4: MPU-6050; InvenSense_QFN-24_4x4mm_P0.5mm

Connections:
3V3: C2.1, C3.1, C6.1, C7.1, C8.1, C9.1, C11.1, J3.4 (VDD), J4.1, R4.1, R5.1, R6.1, R7.1, R8.1, R9.1, U1.2 (3V3), U3.5 (V_{OUT})
D+: J1.3 (D+), R13.2
D-: J1.2 (D-), R12.2
EN: C12.1, EN1.1, J4.5, R4.2, U1.3 (EN)
GND: C1.2, C1#2.1, C2.2, C3.2, C4.2, C5.1, C7.2, C8.2, C9.2, C10.2, C11.2, C12.2, C13.2, EN1.2, IO0.2, J1.5 (GND), J1.6 (Shield), J2.2, J3.6 (VSS), J3.10 (DET_A), J3.11 (SHIELD), J4.2, R1.2, R11.2, U1.1 (GND), U1.40 (GND), U1.41 (GND), U2.1 (TEMP), U2.3 (GND), U2.9 (EPAD), U3.2 (V_{SS}), U4.1 (CLKIN), U4.9 (AD0), U4.18 (GND)
IO0: IO0.1, J4.6, R5.2, U1.27 (IO0)
MPU_INTERUPT: U1.15 (IO3), U4.12 (INT)
MPU_SCL: R7.2, U1.17 (IO9), U4.23 (SCL)
MPU_SDA: R6.2, U1.12 (IO8), U4.24 (SDA)
unnamed: D1.2 (A), R3.2
unnamed: D1.1 (K), U2.7 (~CHRG)
unnamed: D2.2 (A), R2.2
unnamed: D2.1 (K), U2.6 (~STDBY)
unnamed: J1.1 (VBUS), R2.1, R3.1, U2.4 (V_{CC}), U2.8 (CE)
unnamed: J3.8 (DAT1), R9.2
unnamed: J3.1 (DAT2), R8.2
unnamed: R13.1, U1.14 (USB_D+)
unnamed: R12.1, U1.13 (USB_D-)
unnamed: R1.1, U2.2 (PROG)
unnamed: C4.1, U4.20 (CPOUT)
unnamed: C5.2, U4.10 (REGOUT)
unnamed: C6.2, U4.8 (VLOGIC), U4.13 (VDD)
RX: J4.4, U1.36 (RXD0)
SD_CS: J3.2 (DAT3/CD), U1.18 (IO10)
SD_DETECT: J3.9 (DET_B), U1.38 (IO2)
SD_MISO: J3.7 (DAT0), U1.21 (IO13)
SD_MOSI: J3.3 (CMD), U1.19 (IO11)
SD_SCK: J3.5 (CLK), U1.20 (IO12)
TX: J4.3, U1.37 (TXD0)
VBAT: C1#2.2, C13.1, J2.1, R10.1, U2.5 (BAT), U3.1 (V_{IN}), U3.3 (CE)
VBAT_SENSE: C10.1, R10.2, R11.1, U1.39 (IO1)

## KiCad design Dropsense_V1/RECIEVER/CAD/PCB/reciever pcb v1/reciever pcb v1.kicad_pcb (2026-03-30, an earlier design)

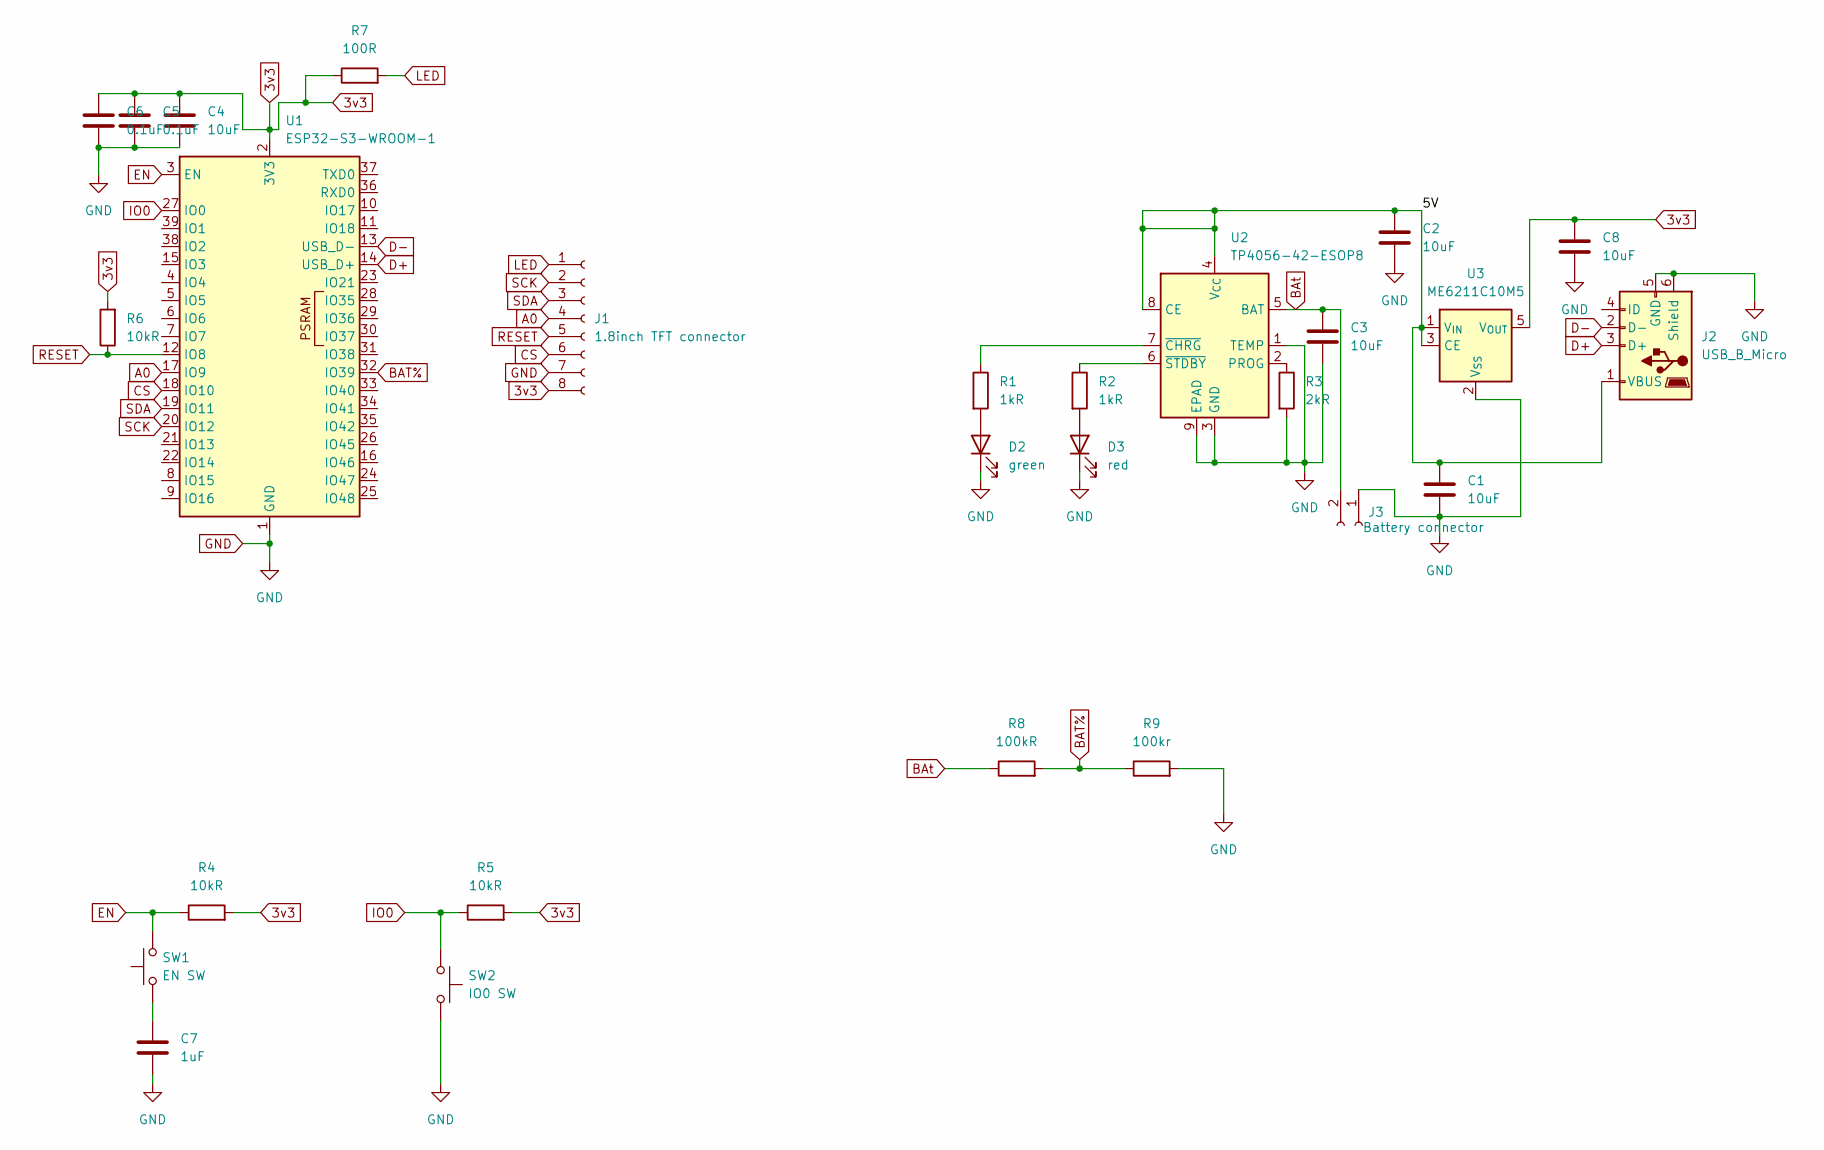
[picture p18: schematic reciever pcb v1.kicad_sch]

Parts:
C1, C2, C3, C4, C8: 10uF; C_0805_2012Metric
C5, C6: 0.1uF; C_0805_2012Metric
C7: 1uF; C_0805_2012Metric
D2: green; LED_0805_2012Metric
D3: red; LED_0805_2012Metric
J1: 1.8inch TFT connector; PinSocket_1x08_P2.54mm_Vertical
J2: USB_B_Micro; USB_Micro-B_Technik_TWP-4002D-H3
J3: Battery connector; JST_XH_S2B-XH-A_1x02_P2.50mm_Horizontal
R1, R2: 1kR; R_0805_2012Metric
R3: 2kR; R_0805_2012Metric
R4, R5, R6: 10kR; R_0805_2012Metric
R7: 100R; R_0805_2012Metric
R8: 100kR; R_0805_2012Metric
R9: 100kr; R_0805_2012Metric
SW1: EN SW; SW_PUSH_6mm_H4.3mm
SW2: IO0 SW; SW_PUSH_6mm_H4.3mm
U1: ESP32-S3-WROOM-1
U2: TP4056-42-ESOP8; SOIC-8-1EP_3.9x4.9mm_P1.27mm_EP2.41x3.3mm_ThermalVias
U3: ME6211C10M5; SOT-23-5

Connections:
3v3: C4.1, C5.1, C6.1, C8.1, J1.8, R4.2, R5.2, R6.2, R7.1, U1.2 (3V3), U3.5 (V_{OUT}); also elsewhere on the board
/5V: C1.1, C2.1, J2.1 (VBUS), U2.4 (V_{CC}), U2.8 (CE), U3.1 (V_{IN}), U3.3 (CE)
A0: J1.4, U1.17 (IO9)
BAT%: R8.2, R9.1, U1.32 (IO39)
BAt: C3.1, J3.2, R8.1, U2.5 (BAT)
CS: J1.6, U1.18 (IO10)
D+: J2.3 (D+), U1.14 (USB_D+)
D-: J2.2 (D-), U1.13 (USB_D-)
EN: R4.1, SW1.2, U1.3 (EN); also elsewhere on the board
GND: C1.2, C2.2, C3.2, C4.2, C5.2, C6.2, C7.2, C8.2, D2.1 (K), D3.1 (K), J1.7, J2.5 (GND), J2.6 (Shield), J3.1, R3.2, R9.2, SW2.2, U1.1 (GND), U1.40 (GND), U1.41 (GND), U2.1 (TEMP), U2.3 (GND), U2.9 (EPAD), U3.2 (V_{SS})
IO0: R5.1, SW2.1, U1.27 (IO0)
LED: J1.1, R7.2
unnamed: C7.1, SW1.1
unnamed: D2.2 (A), R1.2
unnamed: D3.2 (A), R2.2
unnamed: R3.1, U2.2 (PROG)
unnamed: R1.1, U2.7 (~CHRG)
unnamed: R2.1, U2.6 (~STDBY)
RESET: J1.5, R6.1, U1.12 (IO8)
SCK: J1.2, U1.20 (IO12)
SDA: J1.3, U1.19 (IO11)

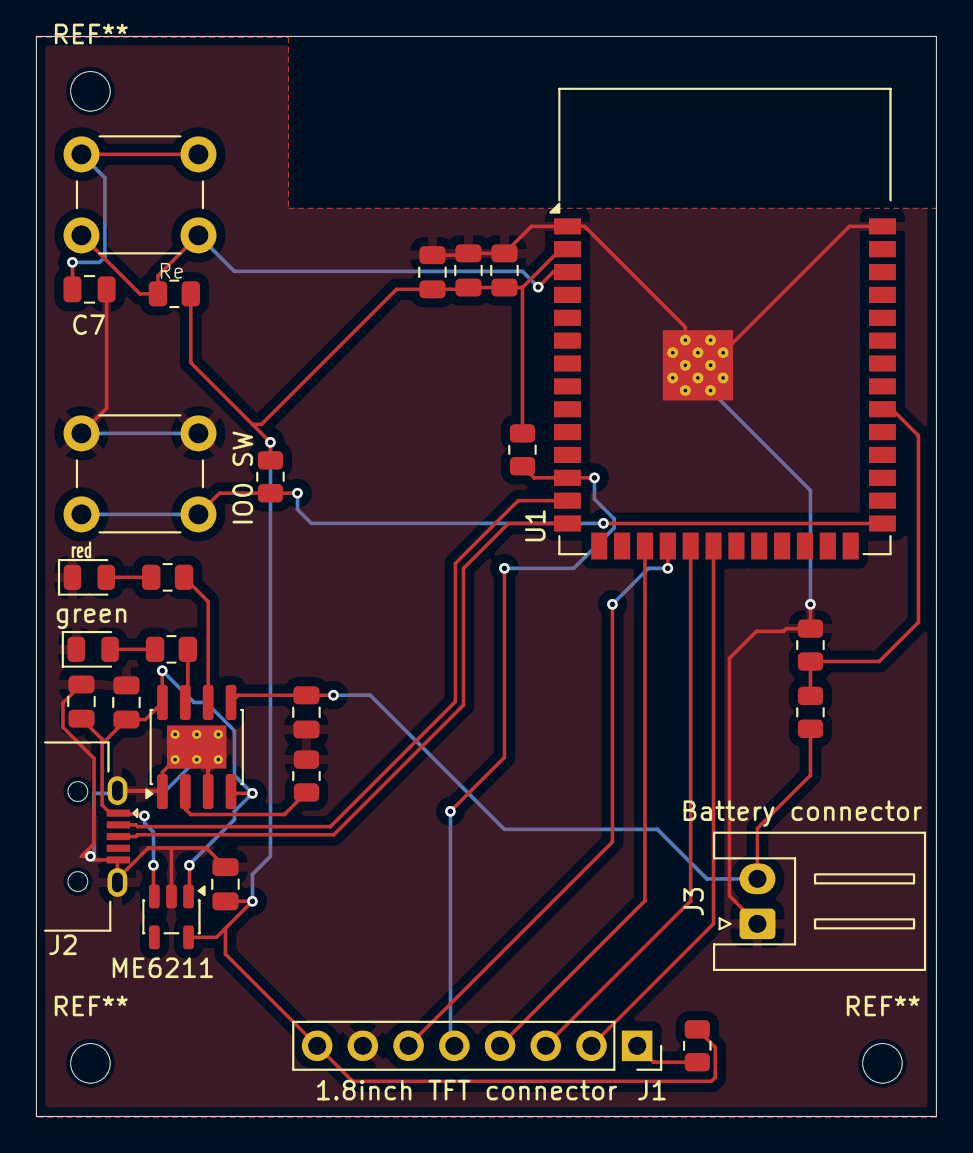
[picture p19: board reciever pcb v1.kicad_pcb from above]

Board: 2 copper layers, 50.0 x 60.0 mm, 27 parts (0 on the bottom side), 21 nets.

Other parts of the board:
Re: 10kR; R_0805_2012Metric

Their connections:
3v3: Re.2; also elsewhere on the board
EN: Re.1; also elsewhere on the board

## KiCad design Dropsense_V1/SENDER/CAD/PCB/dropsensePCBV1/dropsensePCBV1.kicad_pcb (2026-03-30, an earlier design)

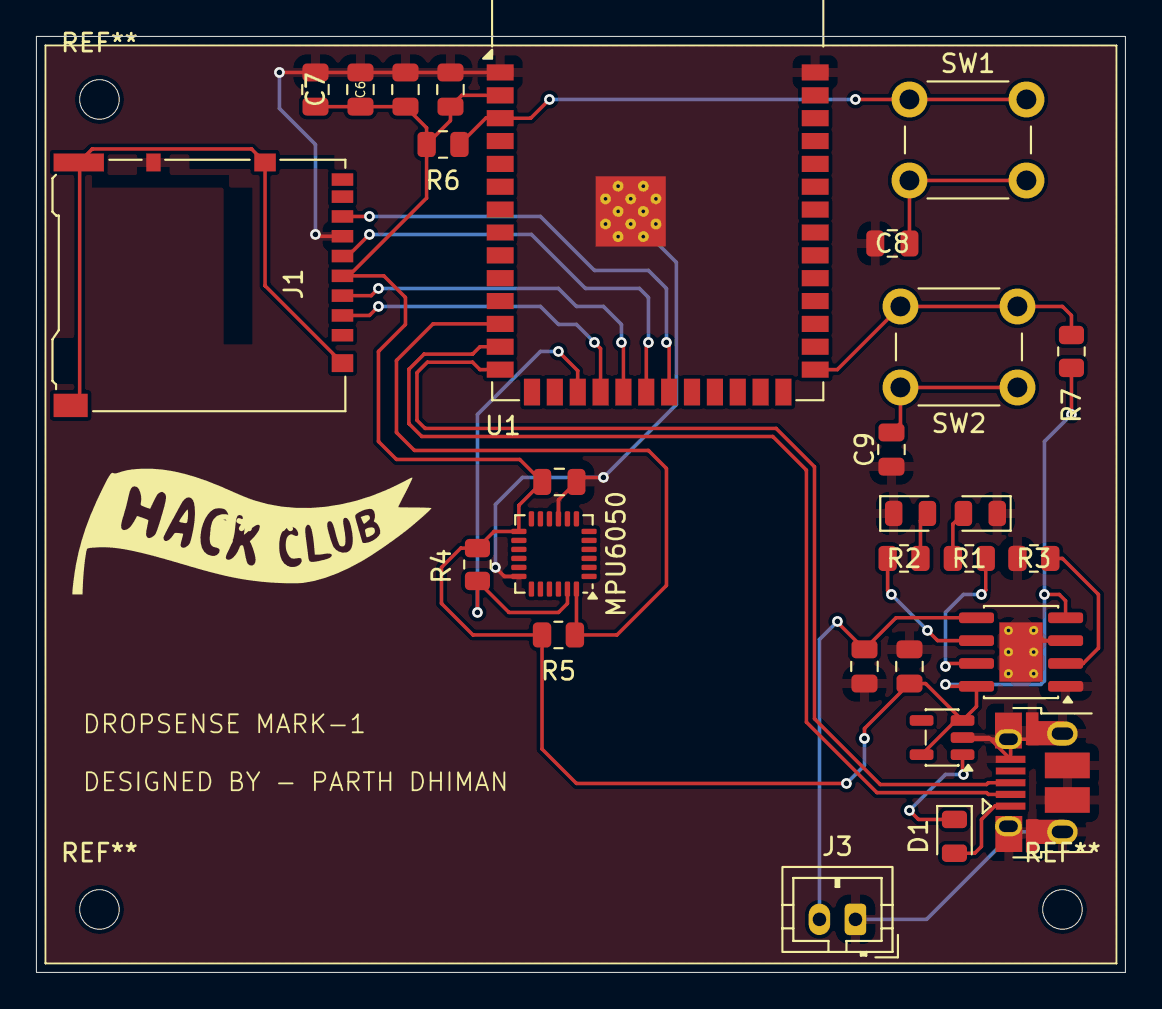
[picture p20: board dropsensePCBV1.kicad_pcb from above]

Board: 2 copper layers, 60.5 x 52.0 mm, 28 parts (0 on the bottom side), 22 nets.

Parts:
C1, C3, C6: 0.1uF; C_0805_2012Metric
C2, C4, C5, C8, C9: 10uF; C_0805_2012Metric
C7: 100uF; C_0805_2012Metric
D1: D_Schottky; D_0805_2012Metric
D2: green; LED_0805_2012Metric
D3: red; LED_0805_2012Metric
J1: Micro_SD_Card_Det_Hirose_DM3AT; microSD_HC_Hirose_DM3AT-SF-PEJM5
J2: USB_B_Micro; USB_Micro-B_Amphenol_10103594-0001LF_Horizontal
J3: battery socket; JST_PH_B2B-PH-K_1x02_P2.00mm_Vertical
MPU6050: MPU-6050; InvenSense_QFN-24_4x4mm_P0.5mm
R1, R2: 330R; R_0805_2012Metric
R3: 1.2R; R_0805_2012Metric
R4, R5: 4.7R; R_0805_2012Metric
R6, R7: 10R; R_0805_2012Metric
SW1, SW2: SW_Push; SW_PUSH_6mm_H4.3mm
U1: ESP32-S3-WROOM-1
U3: TP4056-42-ESOP8; SOIC-8-1EP_3.9x4.9mm_P1.27mm_EP2.41x3.3mm_ThermalVias
U4: ME6211C10M5; SOT-23-5

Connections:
3v3: C2.1, C3.2, C4.1, C5.1, C6.1, C7.2, J1.4 (VDD), MPU6050.13 (VDD), R4.1, R5.1, R6.1, R7.2, U1.2 (3V3), U3.4 (V_{CC}), U3.8 (CE), U4.3 (CE), U4.5 (V_{OUT})
/+ve: C1.1, J3.2, U3.5 (BAT)
D+: J2.3 (D+), U1.14 (USB_D+)
D-: J2.2 (D-), U1.13 (USB_D-)
GND: C1.2, C2.2, C3.1, C4.2, C5.2, C6.2, C7.1, C8.2, C9.2, D2.1 (K), D3.1 (K), J1.6 (VSS), J1.10 (DET_A), J2.5 (GND), J2.6 (Shield), J3.1, MPU6050.9 (AD0), MPU6050.18 (GND), R3.2, U1.1 (GND), U1.40 (GND), U1.41 (GND), U3.1 (TEMP), U3.3 (GND), U3.9 (EPAD), U4.2 (V_{SS})
IO0: R7.1, SW2.2, U1.27 (IO0)
MISO: J1.7 (DAT0), U1.21 (IO13)
MOSI: J1.3 (CMD), U1.19 (IO11)
unnamed: C8.1, SW1.2
unnamed: C9.1, SW2.1
unnamed: D1.2 (A), J2.1 (VBUS)
unnamed: D1.1 (K), U4.1 (V_{IN})
unnamed: D2.2 (A), R1.2
unnamed: D3.2 (A), R2.2
unnamed: R6.2, SW1.1, U1.3 (EN)
unnamed: R3.1, U3.2 (PROG)
unnamed: R1.1, U3.7 (~CHRG)
unnamed: R2.1, U3.6 (~STDBY)
SCL: MPU6050.23 (SCL), R4.2, U1.17 (IO9)
SCk: J1.5 (CLK), U1.20 (IO12)
SDA: MPU6050.24 (SDA), R5.2, U1.12 (IO8)
gpio10: J1.2 (DAT3/CD), U1.18 (IO10)

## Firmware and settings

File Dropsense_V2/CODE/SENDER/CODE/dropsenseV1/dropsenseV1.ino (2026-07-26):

#include <Adafruit_MPU6050.h>
#include <Wire.h>
#include <SPI.h>
#include <SD.h>
#include "WiFi.h"
#include <esp_now.h>

// Pin Definitions according to Schematic
const int SD_CS_PIN   = 10;
const int SD_MOSI_PIN = 11;
const int SD_SCK_PIN  = 12;
const int SD_MISO_PIN = 13;

const int SDA_PIN     = 8;
const int SCL_PIN     = 9;

uint8_t broadcastAddress[] = {0xC8, 0x2E, 0x18, 0xF7, 0x8F, 0xAC};

Adafruit_MPU6050 mpu;
Adafruit_Sensor *mpu_ax, *mpu_gr;

File droplog; 

float fallTime = 0;  
float height = 0;
float maxG = 0;
float gForce = 0;

bool fall = false;
bool isStatic = true;
bool impt = false;

String event = "stat";

unsigned long fallstart = 0;
unsigned long impact = 0;

typedef struct struct_message  {
  float falltime1;
  float height1;
  float maxG1;
  float gForce1; 

} struct_message;

struct_message dropdat;

esp_now_peer_info_t peerInfo;


void setup() {
  Serial.begin(115200);
  WiFi.mode(WIFI_STA);
  Serial.println(WiFi.macAddress());

  if (esp_now_init() != ESP_OK){
    Serial.println("Error initializing esp-now");
    return;
  }

  esp_now_register_send_cb(senddata);

  memcpy(peerInfo.peer_addr, broadcastAddress, 6);
  peerInfo.channel = 0;
  peerInfo.encrypt = false;

  if (esp_now_add_peer(&peerInfo) != ESP_OK){
    Serial.println("Failed to add peer");
    return;
  }

  while (!Serial) delay(10);

  Serial.println("MPU6050 + SD test");

  // Initialize custom I2C pins (SDA = 8, SCL = 9)
  Wire.begin(SDA_PIN, SCL_PIN);

  if (!mpu.begin(0x68, &Wire)) {
    Serial.println("Failed to find MPU6050 chip");
    while (1) delay(10);
  }

  Serial.println("MPU6050 Found!");

  mpu.setAccelerometerRange(MPU6050_RANGE_16_G);

  mpu_ax = mpu.getAccelerometerSensor();
  mpu_gr = mpu.getGyroSensor();

  mpu_ax->printSensorDetails();
  mpu_gr->printSensorDetails();

  // Initialize custom SPI pins for SD card
  SPI.begin(SD_SCK_PIN, SD_MISO_PIN, SD_MOSI_PIN, SD_CS_PIN);

  if (!SD.begin(SD_CS_PIN)) {
    Serial.println("SD init failed!");
    while (1);
  }

  Serial.println("SD ready!");

  droplog = SD.open("/droplog.csv", FILE_WRITE);

  if (droplog) {
    droplog.println("time,gForce,event");
    droplog.close();
  }
}

void loop() {

  readmpu();
  status();
  hndlimpt();
  logdata();

  delay(1);
}

void readmpu(){
  sensors_event_t ax;
  sensors_event_t gr;

  mpu_ax->getEvent(&ax);
  mpu_gr->getEvent(&gr);

  float ax_val = ax.acceleration.x;
  float ay_val = ax.acceleration.y;
  float az_val = ax.acceleration.z;

  float rawG = sqrt(ax_val * ax_val + ay_val * ay_val + az_val * az_val) / 9.81;

  gForce = rawG;

  if(rawG > maxG){
    maxG = rawG;
  }
}

void status(){
  if (gForce < 0.30 && gForce > 0 && !fall) {
    fall = true;
    isStatic = false;
    impt = false;
    event = "fall";
  }

  else if (gForce > 0.85 && gForce < 1.5) {
    fall = false;
    isStatic = true;
    impt = false;
    event = "stat";
  }

  else if (gForce > 5 && fall) {  
    impt = true;
    event = "impt";
  }
}

void hndlimpt(){
  static bool fallstarted = false;
  static bool impactdetected = false;

  if (fall && !fallstarted){
    fallstarted = true;
    fallstart = millis();
    Serial.println("FALLING...");
  }

  else if (impt && !impactdetected){
    impactdetected = true;
    impact = millis();
    Serial.println("IMPACT DETECTED!!!");

    fallTime = (impact - fallstart) / 1000.0;
    height = 0.5 * 9.8 * fallTime * fallTime;
    height *= 1.3;   

    Serial.print("TIME PERIOD = ");
    Serial.println(fallTime);

    Serial.print("HEIGHT = ");
    Serial.println(height);

    Serial.print("PEAK GFORCE = ");   
    Serial.println(maxG);

    setdatstosend();

  }

  if (impt){
    delay(2000);

    maxG = 0;   

    fall = false;
    impt = false;
    event = "stat";

    fallstarted = false;
    impactdetected = false;
  }
}

void logdata(){ 
  droplog = SD.open("/droplog.csv", FILE_APPEND); 

  if (droplog) {
    droplog.print(millis());
    droplog.print(",");
    droplog.print(gForce);
    droplog.print(",");
    droplog.println(event);
    droplog.close();
  }
}

void smoothGForce() {
  static float prevG = 0;   
  float alpha = 0.7;

  gForce = alpha * prevG + (1 - alpha) * gForce;
  prevG = gForce;
}

void senddata(const wifi_tx_info_t *info, esp_now_send_status_t status){
  Serial.print("data sent");
  Serial.println(status == ESP_NOW_SEND_SUCCESS ? "DELIVERY SUCCESS" : "DELIVERY FAIL");
}

void setdatstosend(){
  dropdat.falltime1 = fallTime;
  dropdat.height1 = height;
  dropdat.maxG1 = maxG;
  dropdat.gForce1 = gForce;

  esp_err_t result = esp_now_send(broadcastAddress, (uint8_t *)
   &dropdat, sizeof(dropdat));

   if(result == ESP_OK){
    Serial.print("sent with success");
   }

   else{
    Serial.println("error sending dats");
   }
  delay(10);
}

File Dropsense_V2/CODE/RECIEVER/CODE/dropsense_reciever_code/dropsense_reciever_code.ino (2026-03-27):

#include <WiFi.h>    
#include <esp_wifi.h>
#include <esp_now.h>
#include <Adafruit_ST7735.h>
#include <SPI.h>
#include <Adafruit_GFX.h>

#define TFT_CS  5
#define TFT_DC  2
#define TFT_RST 4

Adafruit_ST7735 tft = Adafruit_ST7735(TFT_CS, TFT_DC, TFT_RST);

typedef struct struct_message  {
  float falltime1;
  float height1;
  float maxG1;
  float gForce1; 

} struct_message;

struct_message dropdat;

void setup(){
  Serial.begin(115200);

  tft.initR(INITR_BLACKTAB);
  tft.setRotation(3);
  tft.fillScreen(ST77XX_BLACK);

  WiFi.mode(WIFI_STA);

  if(esp_now_init() != ESP_OK){
    Serial.println("Error initializing ESP_NOW");
    return;
  }

  esp_now_register_recv_cb(recievedata);
}
 
void loop(){
}

void recievedata(const esp_now_recv_info_t *info, const uint8_t *incomingData, int len){
  memcpy(&dropdat, incomingData, sizeof(dropdat));

  Serial.print("bytes recieved");
  Serial.println(len);
  Serial.print("falltime ");
  Serial.println(dropdat.falltime1);
  Serial.print("height");
  Serial.println(dropdat.height1);
  Serial.print("maxGforce");
  Serial.println(dropdat.maxG1);

  tft.fillScreen(ST77XX_BLACK);

  tft.setTextColor(ST77XX_RED);
  tft.setTextSize(2);
  tft.setCursor(10, 5);
  tft.println("IMPACT!!!!");

  tft.setTextColor(ST77XX_WHITE);
  tft.setTextSize(1);

  tft.setCursor(0, 35);
  tft.print("Time: ");

  tft.setTextColor(ST77XX_YELLOW);
  tft.setTextSize(2);
  tft.println(dropdat.falltime1);

  tft.setTextColor(ST77XX_WHITE);
  tft.setTextSize(1);
  tft.setCursor(0, 65);
  tft.print("Height: ");

  tft.setTextColor(ST77XX_CYAN);
  tft.setTextSize(2);
  tft.println(dropdat.height1);

  tft.setTextColor(ST77XX_WHITE);
  tft.setTextSize(1);
  tft.setCursor(0, 95);
  tft.print("Peak G: ");

  tft.setTextColor(ST77XX_GREEN);
  tft.setTextSize(2);
  tft.println(dropdat.maxG1);

  delay(100);
}

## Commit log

2026-03-24 Code V2
    updated the code improved the functionality better variable names
    added sd card functioanlity
    [droplog V2.csv, droplog.csv]
2026-03-24 added wiring.csv file
    [WIRING DIGRAMS (for prototype).csv]
2026-03-25 started rough pcb design
    [dropsensePCBV1.kicad_pcb, dropsensePCBV1.kicad_sch]
2026-03-25 Update WIRING DIGRAMS (for prototype).csv
    added guide to open the file in microsoft excel for proper viewing
    [WIRING DIGRAMS (for prototype).csv]
2026-03-25 STARTED PCB SCHEMATICS WORK
    started pcb schematics work and finished the schematics
2026-03-25 saved pcb files in device
    [dropsensePCBV1.kicad_pcb, dropsensePCBV1.kicad_sch]
2026-03-25 PCB DESIGN OF DROPSENSE V1 COMPLETED
    [dropsensePCBV1-B_Cu.gbr, dropsensePCBV1-B_Mask.gbr, dropsensePCBV1-B_Paste.gbr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]
2026-03-25 UPDATED DROPSENSE PCB
    [dropsensePCBV1.kicad_pcb, dropsensePCBV1.kicad_sch]
2026-03-27 development of dropsense reciever code
    [WIRING DIGRAMS (for prototype).csv, droplog V2.csv, droplog.csv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]
2026-03-27 created reciever pcv v1
    [reciever pcb v1.kicad_pcb, reciever pcb v1.kicad_sch]
2026-03-28 Routed and finished reciever pcb
    [reciever pcb v1.kicad_pcb, reciever pcb v1.kicad_sch]
2026-03-29 PCB improvement
    updated and polished both the pcbs of the sender and reciever mainly woked on moving viases away from smd components
    [dropsensePCBV1.kicad_pcb, dropsensePCBV1.kicad_sch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]
2026-03-30 made the 3d design and assembly
    made the 3d design and assembly for dropsense reciever
    [Dropsense reciever pcb case v14.f3d, Dropsense reciever pcb case v14.step, dropsense reciever lid v1 v12.f3d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]
2026-03-30 3d design of sender enclosure started
    [dropsensePCBV1.kicad_pcb]
2026-03-31 updated 3d designs and BOM
    [Dropsense sender pcb 3d enclosure part 2 v4.step, Dropsense sender pcn case part 1 v8.step, bom.csv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]
2026-04-01 UPDATED AND PERFECTED bom FILE
    [BOM(with images).xlsx, BOM.csv, bom.csv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]
2026-04-01 updated BOM
    [BOM(with images).xlsx, BOM.csv]
2026-04-01 UPDATED BOM
    (final bom)
    [BOM(with images).xlsx, BOM.csv]
2026-06-03 updated PCB files
    [dropsensePCBV1.kicad_sch]
2026-06-05 STARTED DROPSENSE V2!!!!!!
    [dropsense_v2.kicad_pcb, dropsense_v2.kicad_sch]
2026-06-05 updates for pcb dropsense v2
    [dropsense_v2.kicad_sch]
2026-06-08 started work on dropsense sender and reciever new pcb
    [bom.csv, designators.csv, dropsense_reciever_v2.kicad_pcb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]
2026-06-09 made dropsense reciever pcb
    [bom.csv, designators.csv, dropsense_reciever_v2.kicad_pcb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]
2026-07-26 Few pre-final updates
    [Dropsense Makr-2 reciever assembly v1.step, Dropsense Mark-2 reciever part-2 v8.f3d, Dropsense Mark-2 reciever part-2 v8.step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]
2026-07-26 Final arrangements
    [BOM(with images).xlsx, BOM.csv, droplog V2.csv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]
